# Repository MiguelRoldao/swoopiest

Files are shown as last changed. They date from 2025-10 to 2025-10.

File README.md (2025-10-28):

# The Swoopiest

A keyboard based on the iconic [Swoop]() and the adored [Kyria]().

## Gudhowboutya?

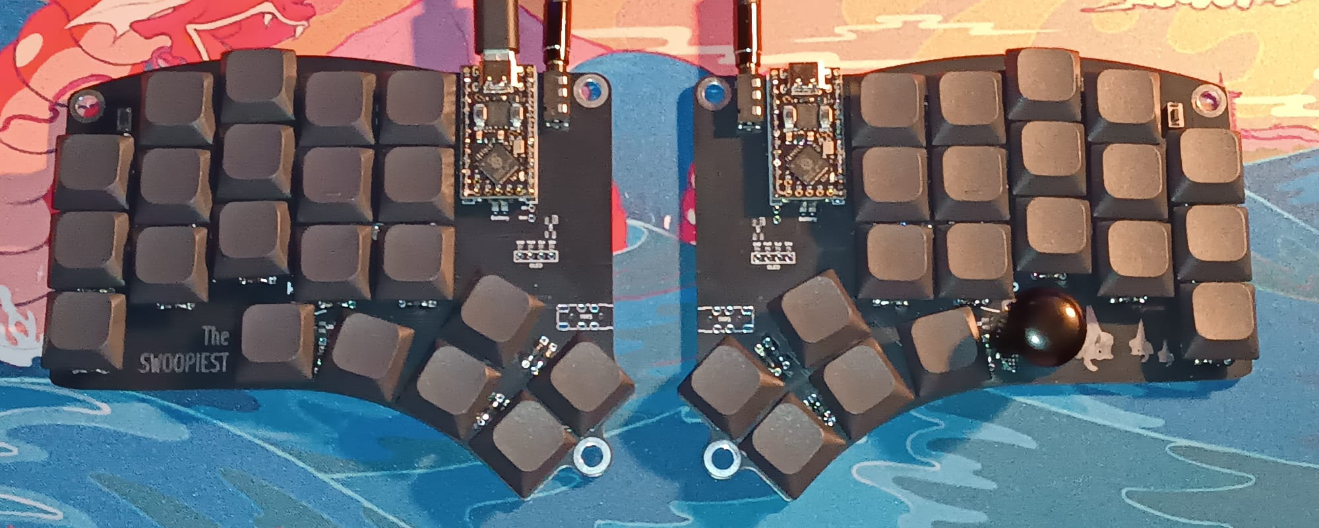
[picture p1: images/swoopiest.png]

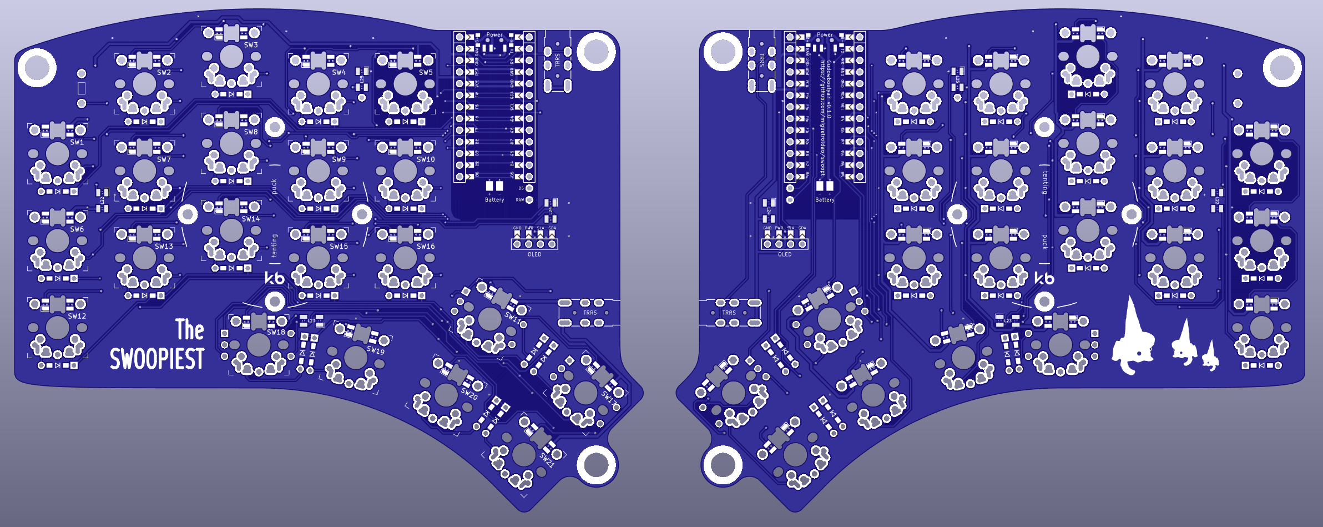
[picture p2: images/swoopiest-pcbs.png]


## Features
* Soldered universal switch footprint (not hot-swappable)
* Reversible PCB
* Per-key RGB LEDs (mini-e)
* RGB LED underglow
* Up to 2 encoders
* Oled screens
* Power switch for battery management
* Bluetooth support w/ nice!nano or nrf52840
* Tenting puck compatible
* M5 screw holes for cheap tenting

## Components list

To build and use *The Swoopiest* you will need:

* 2× Reversible PCBs
* 2× ProMicro compatible boards or 2 nice!nanos (for headers, the [nrf52840 repo](https://github.com/joric/nrfmicro/wiki/Sockets#machine-pins) has great info)
* 40-42× Keyboard switches
* 40-42× Keycaps 1u
* 40-42× SK6812 Mini-E RGB SMD Leds (optional; not recommended for wireless)
* 40-42× SK6812 3535 RGB SMD Leds (optional; not recommended for wireless)
* 42× diodes (Surface-mount or Through-hole)
* 0-2× Rotary encoders & knobs (optional; ALPS EC11)
* 0-2× OLED LCD Display 128x64 SSD1306 (optional)
* 2× reset switches (optional; (3x6x4.3mm))
* Some little rubber feet/bumpers
* 2× power switches (wireless only; MSK 12C02)
* 2× lipo batteries (wireless only)
* 1× TRRS (See below for more) cable (wired only)
* 2× TRRS Jack [PJ-320A] (wired only)
* 1× USB Cable (depends on your micro-controller choice)  

## Switch compatibility

The universal foot print makes switch incompatibility a thing of the past. The Swoopiest is compatible with most common switch types:
* Choc v1
* Choc v2
* Gateron KS33
* Cherry MX (altough with a bit too much wiggle room. The 5-pin variation fits more snuggly)

With a bit of effort, Reddragon's low profiles also fit by twisting the legs a little bit.

#### The middle pin

The middle pin of the PCB isn't connected to anything (to allow the reversible pcb in conjunction with the universal footprint).
If switches that use the middle pin are chosen (like chocs or reddragons), connect the middle pin to the pads opposite ot the other used pin.
Whether by use of a tiny piece of wire, or with a solder blob.

## Firmware

The firmware is available in my QMK repo as `diaffractus/swoopiest`.  
You can get started by using QMK's [online configurator](https://config.qmk.fm/#/bluebell/swoop/LAYOUT_split_3x5_3). Or check [The Swoopiest README file](https://github.com/MiguelRoldao/qmk-home/blob/master/keyboards/diaffractus/swoopiest/readme.md) to see how to compile the firmware locally.

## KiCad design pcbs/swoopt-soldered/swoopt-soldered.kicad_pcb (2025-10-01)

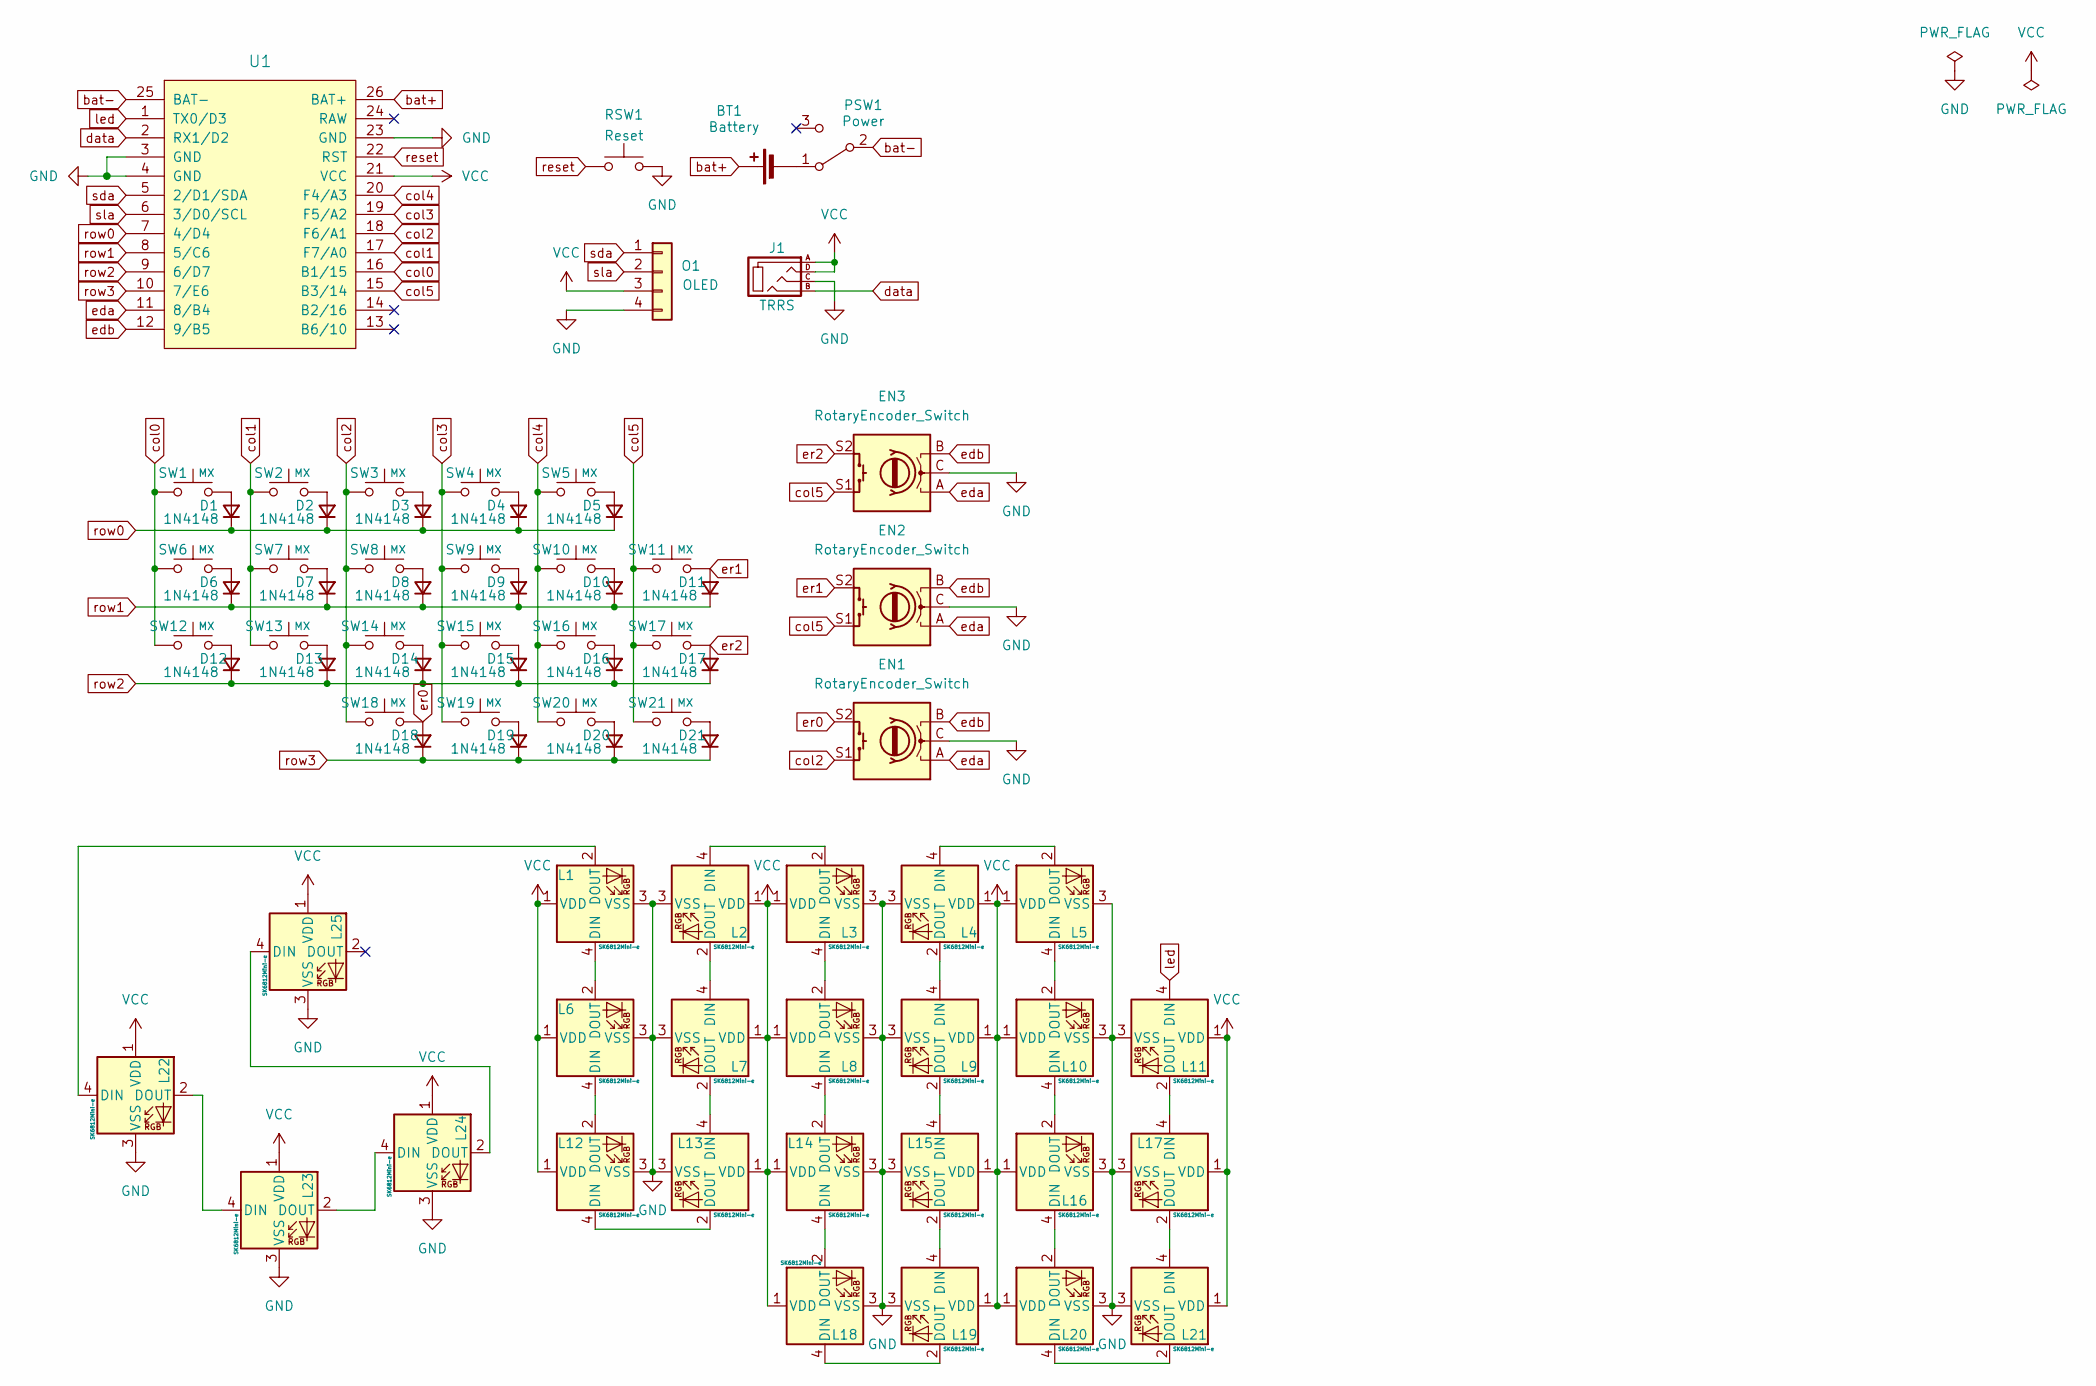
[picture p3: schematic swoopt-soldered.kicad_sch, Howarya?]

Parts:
BT1: Battery; Battery_pads_reversible
D1, D2, D3, D4, D5, D6, D7, D8, D9, D10, D11, D12, D13, D14, D15, D16, D17, D18, D19, D20, D21: 1N4148; D_SMD_TH
EN1, EN2, EN3: RotaryEncoder_Switch; RotaryEncoder
J1: TRRS; TRRS-3pin
L1, L2, L3, L4, L5, L6, L7, L8, L9, L10, L11, L12, L13, L14, L15, L16, L17, L18, L19, L20, L21: SK6812Mini-e; SK6812_Mini_E; JLCPCB BOM 0
L22, L23, L24, L25: SK6812Mini-e; LED_SK6812MINI__3.5x3.5mm_reversible; JLCPCB BOM 0
O1: OLED; OLED_jumpers
PSW1: Power
RSW1: Reset; SW_TH_1TS002A
SW1, SW2, SW3, SW4, SW5, SW6, SW7, SW8, SW9, SW10, SW11, SW12, SW13, SW14, SW15, SW16, SW17, SW18, SW19, SW20, SW21: MX; SW_Universal_TH_Reversible
U1: U_ProMicro_nRF52840_TH_Reversible

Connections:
GND: EN1.C, EN2.C, EN3.C, J1.C, L1.3 (VSS), L2.3 (VSS), L3.3 (VSS), L4.3 (VSS), L5.3 (VSS), L6.3 (VSS), L7.3 (VSS), L8.3 (VSS), L9.3 (VSS), L10.3 (VSS), L11.3 (VSS), L12.3 (VSS), L13.3 (VSS), L14.3 (VSS), L15.3 (VSS), L16.3 (VSS), L17.3 (VSS), L18.3 (VSS), L19.3 (VSS), L20.3 (VSS), L21.3 (VSS), L22.3 (VSS), L23.3 (VSS), L24.3 (VSS), L25.3 (VSS), O1.4, RSW1.2, U1.3 (GND), U1.4 (GND), U1.23 (GND); also elsewhere on the board
unnamed: BT1.2 (-), PSW1.1 (A)
unnamed: D1.2 (A), SW1.2
unnamed: D2.2 (A), SW2.2
unnamed: D3.2 (A), SW3.2
unnamed: D4.2 (A), SW4.2
unnamed: D5.2 (A), SW5.2
unnamed: D6.2 (A), SW6.2
unnamed: D7.2 (A), SW7.2
unnamed: D8.2 (A), SW8.2
unnamed: D9.2 (A), SW9.2
unnamed: D10.2 (A), SW10.2
unnamed: D12.2 (A), SW12.2
unnamed: D13.2 (A), SW13.2
unnamed: D14.2 (A), SW14.2
unnamed: D15.2 (A), SW15.2
unnamed: D16.2 (A), SW16.2
unnamed: D19.2 (A), SW19.2
unnamed: D20.2 (A), SW20.2
unnamed: D21.2 (A), SW21.2
unnamed: L1.4 (DIN), L6.2 (DOUT)
unnamed: L1.2 (DOUT), L22.4 (DIN)
unnamed: L2.4 (DIN), L3.2 (DOUT)
unnamed: L2.2 (DOUT), L7.4 (DIN)
unnamed: L3.4 (DIN), L8.2 (DOUT)
unnamed: L4.4 (DIN), L5.2 (DOUT)
unnamed: L4.2 (DOUT), L9.4 (DIN)
unnamed: L10.4 (DIN), L16.2 (DOUT)
unnamed: L5.4 (DIN), L10.2 (DOUT)
unnamed: L11.2 (DOUT), L17.4 (DIN)
unnamed: L12.4 (DIN), L13.2 (DOUT)
unnamed: L6.4 (DIN), L12.2 (DOUT)
unnamed: L7.2 (DOUT), L13.4 (DIN)
unnamed: L14.4 (DIN), L18.2 (DOUT)
unnamed: L8.4 (DIN), L14.2 (DOUT)
unnamed: L9.2 (DOUT), L15.4 (DIN)
unnamed: L15.2 (DOUT), L19.4 (DIN)
unnamed: L16.4 (DIN), L20.2 (DOUT)
unnamed: L17.2 (DOUT), L21.4 (DIN)
unnamed: L18.4 (DIN), L19.2 (DOUT)
unnamed: L20.4 (DIN), L21.2 (DOUT)
unnamed: L22.2 (DOUT), L23.4 (DIN)
unnamed: L23.2 (DOUT), L24.4 (DIN)
unnamed: L24.2 (DOUT), L25.4 (DIN)
VCC: J1.A, J1.D, L1.1 (VDD), L2.1 (VDD), L3.1 (VDD), L4.1 (VDD), L5.1 (VDD), L6.1 (VDD), L7.1 (VDD), L8.1 (VDD), L9.1 (VDD), L10.1 (VDD), L11.1 (VDD), L12.1 (VDD), L13.1 (VDD), L14.1 (VDD), L15.1 (VDD), L16.1 (VDD), L17.1 (VDD), L18.1 (VDD), L19.1 (VDD), L20.1 (VDD), L21.1 (VDD), L22.1 (VDD), L23.1 (VDD), L24.1 (VDD), L25.1 (VDD), O1.3, U1.21 (VCC); also elsewhere on the board
bat+: BT1.1 (+), U1.26 (BAT+)
bat-: PSW1.2 (B), U1.25 (BAT-)
col0: SW1.1, SW6.1, SW12.1, U1.16 (B1/15)
col1: SW2.1, SW7.1, SW13.1, U1.17 (F7/A0)
col2: EN1.S1, SW3.1, SW8.1, SW14.1, SW18.1, U1.18 (F6/A1)
col3: SW4.1, SW9.1, SW15.1, SW19.1, U1.19 (F5/A2)
col4: SW5.1, SW10.1, SW16.1, SW20.1, U1.20 (F4/A3)
col5: EN2.S1, EN3.S1, SW11.1, SW17.1, SW21.1, U1.15 (B3/14)
data: J1.B, U1.2 (RX1/D2); also elsewhere on the board
eda: EN1.A, EN2.A, EN3.A, U1.11 (8/B4)
edb: EN1.B, EN2.B, EN3.B, U1.12 (9/B5)
er0: D18.2 (A), EN1.S2, SW18.2
er1: D11.2 (A), EN2.S2, SW11.2
er2: D17.2 (A), EN3.S2, SW17.2
led: L11.4 (DIN), U1.1 (TX0/D3)
reset: RSW1.1, U1.22 (RST)
row0: D1.1 (K), D2.1 (K), D3.1 (K), D4.1 (K), D5.1 (K), U1.7 (4/D4)
row1: D6.1 (K), D7.1 (K), D8.1 (K), D9.1 (K), D10.1 (K), D11.1 (K), U1.8 (5/C6)
row2: D12.1 (K), D13.1 (K), D14.1 (K), D15.1 (K), D16.1 (K), D17.1 (K), U1.9 (6/D7)
row3: D18.1 (K), D19.1 (K), D20.1 (K), D21.1 (K), U1.10 (7/E6)
sda: O1.1, U1.5 (2/D1/SDA)
sla: O1.2, U1.6 (3/D0/SCL)

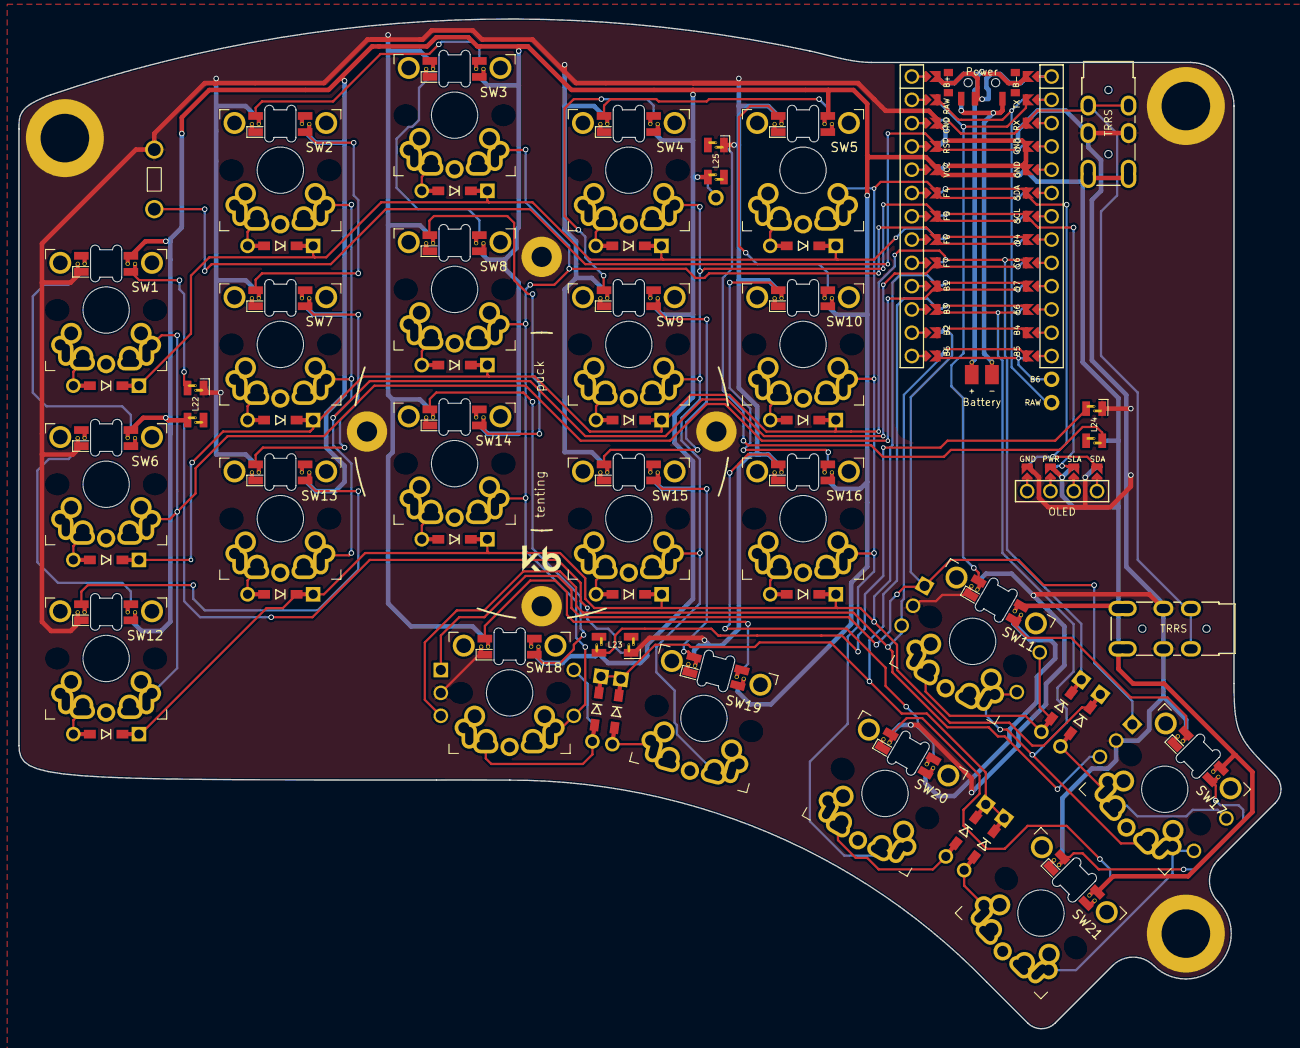
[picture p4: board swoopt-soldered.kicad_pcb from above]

Board: 2 copper layers, 137.6 x 110.1 mm, 77 parts (1 on the bottom side), 67 nets.

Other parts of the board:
J1#2: TRRS; TRRS-3pin

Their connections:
GND: J1#2.C; also elsewhere on the board
VCC: J1#2.A, J1#2.D; also elsewhere on the board
data: J1#2.B; also elsewhere on the board

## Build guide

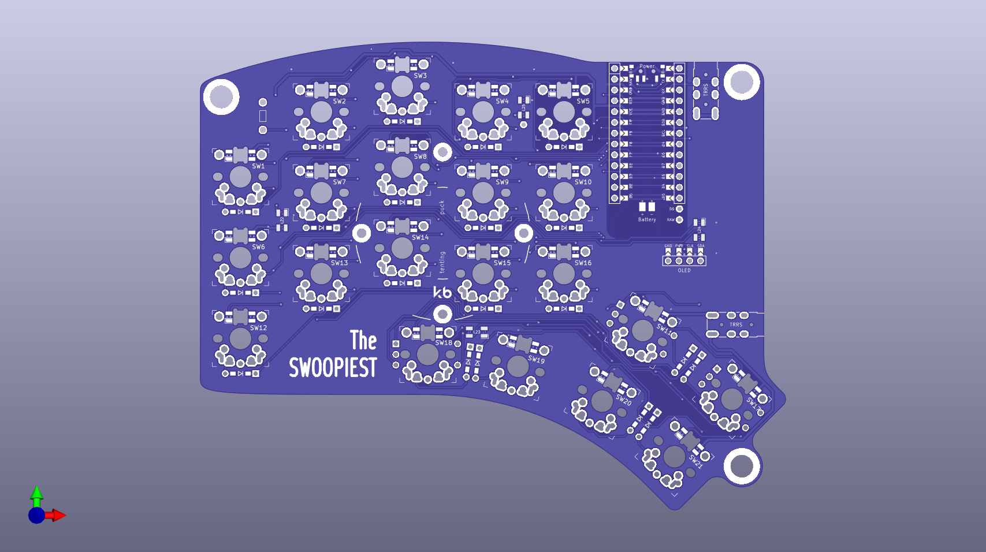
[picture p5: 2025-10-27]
images/swoopt-soldered.png

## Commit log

2025-09-16 updated footprints and traces. Also added Debora.
    [swoopt-soldered.kicad_pcb, swoopt-soldered.kicad_sch]
2025-09-26 added gerbers and missing libraries
    [swoopt-soldered-B_Cu.gbl, swoopt-soldered-B_Mask.gbs, swoopt-soldered-B_Silkscreen.gbo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]
2025-09-26 work on the swoopiest - layout defined
    [swoopt-soldered.kicad_pcb, swoopt-soldered.kicad_sch]
2025-09-27 traces are complete, with second jack
    [swoopt-soldered.kicad_pcb, swoopt-soldered.kicad_sch]
2025-09-30 added underglow leds
    [swoopt-soldered.kicad_pcb, swoopt-soldered.kicad_sch]
2025-10-01 added tenting screw holes, with needed board alterations
    [swoopt-soldered.kicad_pcb]
2025-10-01 added m2 screw holes for mounting
    [swoopt-soldered.kicad_pcb]
2025-10-01 pulled pinky column 2mm down
    [swoopt-soldered.kicad_pcb]
2025-10-01 added tenting puck
    [swoopt-soldered-B_Cu.gbl, swoopt-soldered-B_Mask.gbs, swoopt-soldered-B_Silkscreen.gbo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]
2025-10-26 minor adjustments to pcb
